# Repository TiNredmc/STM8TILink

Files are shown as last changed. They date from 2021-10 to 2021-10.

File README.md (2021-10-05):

# STM8TILink
The TI grey link clone based on arduino code and half duplex code for stm8s (credits after this line). WIP

# credit 
[DSchndr](https://github.com/DSchndr/serial2ti83) fork of [jw0k repo](https://github.com/jw0k/serial2ti83).

# PCB (at OSHpark).
[rev1 PCB](https://oshpark.com/shared_projects/LCwtGfEf).

# Extra
Due to the physical limitation of STM8S001J3 available pin. I was forced to use the single wire bi-directional UART. which it means that I share TX and RX on same pin (based on [This guy work](http://ficara.altervista.org/?p=4047&doing_wp_cron=1633419018.3038520812988281250000)). The problem starts when host send data to CH330N, since the TX is  connected to schottky barrier diode on cathod side, anode side is connected to STM8 (with 4.7k pull up) and RX pin of CH330N. The loopback "echo" occured everytime the host send command to STM8. The CH330N doesn't ignore the RX line when TX is transmitting. SO the host confused that the RX data is valid (which is not!). In order to solve this problem. I redesigned the PCB with included the SN74LVC1G3157DBVR, SPDT analog switch. I use this IC for bus isolation. CH330N RX will be isolated when MCU isn't send any data to host, it will left unconnected all the time to prevent the loopback echo and confuse host device.

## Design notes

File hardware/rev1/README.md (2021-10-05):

# BOMs

1. x1 BAT43 smd sot-323 diode.  
2. x4 1uF 0603.  
3. x1 CH330N USB to UART 
4. x3 10kOhm or 4.7kOhm 0603.
5. x1 SN74LVC1G3157 SOT-23-6.
6. x1 STM8S001J3.
7. x1 2.5mm 3-pole audio jack (TI plug).

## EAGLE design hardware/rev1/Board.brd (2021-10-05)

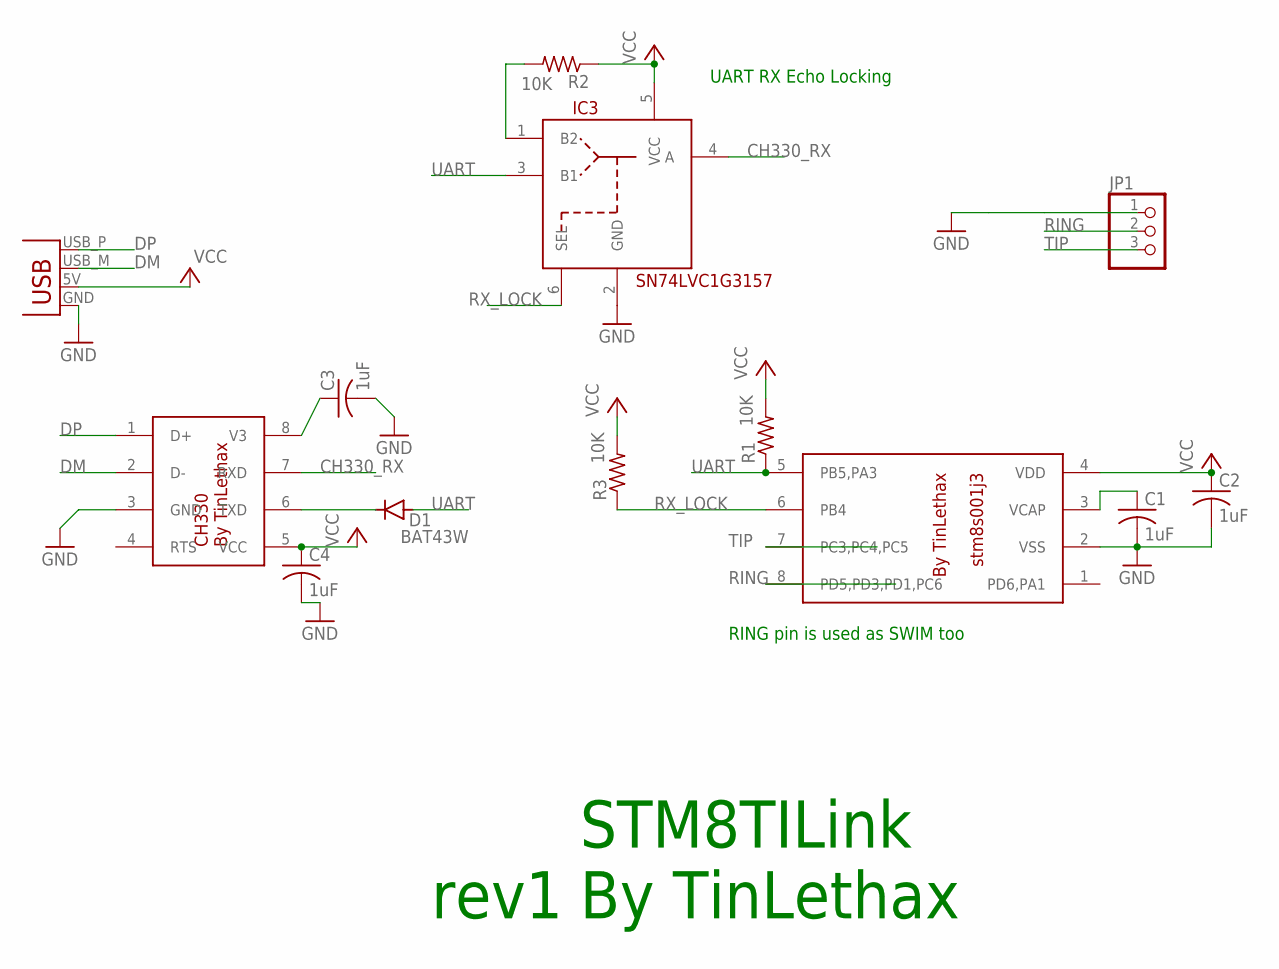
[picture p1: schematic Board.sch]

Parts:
C1, C2, C3, C4: 1uF; C0603
D1: BAT43W; SOD-123_MINI-SMA
IC1: STM8S001J3; SOP8
IC2: CH330; SOIC127P600X150-8N
IC3: SN74LVC1G3157; SOT95P280X145-6N
JP1: PINHD-1X3; 1X03
R1, R2, R3: 10K; R0603
X1: USB_USBPCB; USB_USB-A-PCB

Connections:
CH330_RX: IC2.7 (RXD), IC3.4 (A)
DM: IC2.2 (D-), X1.USB_M (D-)
DP: IC2.1 (D+), X1.USB_P (D+)
GND: C1.2, C2.2, C3.2, C4.2, IC1.2 (VSS), IC2.3 (GND), IC3.2 (GND), JP1.1, X1.GND
unnamed: C1.1, IC1.3 (VCAP)
unnamed: IC3.1 (B2), R2.2
unnamed: C3.1, IC2.8 (V3)
unnamed: D1.C, IC2.6 (TXD)
RING: IC1.8 (PD5,PD3,PD1,PC6), JP1.2
RX_LOCK: IC1.6 (PB4), IC3.6 (SEL), R3.1
TIP: IC1.7 (PC3,PC4,PC5), JP1.3
UART: D1.A, IC1.5 (PB5,PA3), IC3.3 (B1), R1.1
VCC: C2.1, C4.1, IC1.4 (VDD), IC2.5 (VCC), IC3.5 (VCC), R1.2, R2.1, R3.2, X1.5V (VBUS)

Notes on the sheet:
STM8TILink By TinLethax
RING pin is used as SWIM too
rev1
UART RX Echo Locking

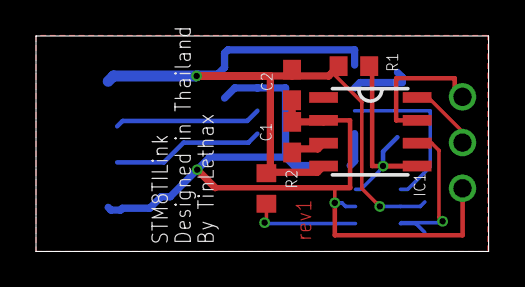
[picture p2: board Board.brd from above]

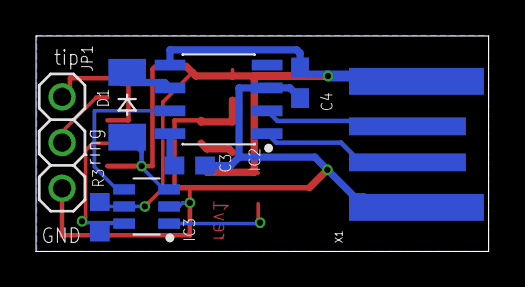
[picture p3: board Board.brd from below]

Board: 2 copper layers, 25.1 x 12.0 mm, 13 parts (8 on the bottom side), 13 nets.

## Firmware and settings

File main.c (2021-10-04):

////////////////////////////////////////////////////////////////////////////////
// FW_VERSION  180701 (yymmdd) - Author: Emilio P.G. Ficara
// Modified to use with STM8TI by TinLethax
// V180701

#include <stm8s.h> // DO NOT USE here generic iostm8s.h (register map is different)
#include <delay.h>
#include <stdint.h>
#include <stdbool.h>

/* TIM4 stuffs */
// arr value for TIM4 millis() interupt.
#define TOP1MS		124 // Tim4 compare top value for 1mS tick
// millis() return value
volatile uint16_t mil = 0;
uint16_t millis(void);

/* UART stuffs */
volatile uint8_t echo = 0; // flag for "RX data is echo of TX"
volatile uint8_t DataFlag = 0;
volatile uint8_t revDat[4] = {0}; //data receive over the UART

/* variables for TI stuffs */

const uint8_t TIP = 5; //PC5 Tip pin
const uint8_t RING = 6; //PC6 Ring pin
const uint8_t TXTIMEOUT = 70; //50ms
const uint8_t RXTIMEOUT = 40; //20ms


#define TI_TIP_IS_HIGH   (PC_IDR & 0x10) 
#define TI_RING_IS_HIGH (PC_IDR & 0x20)

#define TI_TIP_IS_LOW   (~PC_IDR & 0x10)
#define TI_RING_IS_LOW  (~PC_IDR & 0x20)

void TiTipLow(){
	PC_ODR &= ~(1 << TIP);   
}

void TiRingLow(){
	PC_ODR &= ~(1 << RING);   
}

void TiTipOutput(){
	PC_DDR |= (1 << TIP);
	PC_CR1 |= (1 << TIP);
}

void TiRingOutput(){
	PC_DDR |= (1 << RING);
	PC_CR1 |= (1 << RING);
}

void TiTipInputHigh(){
	PC_DDR &= ~(1 << TIP);
	PC_CR1 |= (1 << TIP);
}

void TiRingInputHigh(){
	PC_DDR &= ~(1 << RING);
	PC_CR1 |= (1 << RING);
}


//------------------------------------------------------------------------------
// Serial COMM section

void OutCom(unsigned char c)// sending single byte from calc to PC
{
	echo = 1; // set echo flag (TX will be immediatly received on RX)
	while((UART1_SR & 0x80) == 0); // wait for TXE = 1
	UART1_DR = c; // send char
	while(echo); // wait until echo received
}

//------------------------------------------------------------------------------
// Interrupts section
//
void tim4_millis_irq(void) __interrupt(23)// The millis part, every 1 ms
{
     TIM4_SR = 0x00; // clear irq flag
     mil++;
}

void USART1_RX(void) __interrupt(18){ // Deal with the incoming data from PC and soon will transfer to calc

uint8_t e;

	e = UART1_SR; // read / clear (and ignore) error flags
	e = 1;
	revDat[0] = UART1_DR; // get the char and clear irq
	if(echo){ // if received data is echo of TX
		echo = 0; // turn off flag and don't save
	}else{
		while(UART1_SR & 0x20)// wait until buffer is empty
		revDat[e++] = UART1_DR;// reading all data from host.
		
		DataFlag = 1;// incoming data is not echo but it's data to send to Ti calc.
	}

}

////////////////////////////////////////////////////////////////////////////////
// Stuff for millis(); and TI stuff
//
uint16_t millis(){
return (uint16_t)mil;
}

void sendByte(uint8_t byte){
    uint16_t currentTime;

    for (uint8_t i = 0; i < 8; ++i){
        bool bit = byte & 0x01;
        byte >>= 1;

        //poll both lines until they are both high, which means we're ready to send a bit
        currentTime = millis();
        while (TI_TIP_IS_LOW || TI_RING_IS_LOW){
            if (millis() - currentTime > TXTIMEOUT){
                return;
            }
        }

        if (bit){
            // send a bit by pulling appropriate line low
            TiRingOutput();
            TiRingLow();

            // wait for opposite line to become low
            currentTime = millis();
            while (TI_TIP_IS_HIGH){
                if (millis() - currentTime > TXTIMEOUT){
                    TiRingInputHigh();// set to input pull up.
                    return;
                }
            }

            // release our line
            TiRingInputHigh();

            // wait for opposite line to become high
            currentTime = millis();
            while (TI_TIP_IS_LOW){
                if (millis() - currentTime > TXTIMEOUT){
                    return;
                }
            }

        }else{
            // send a bit by pulling appropriate line low
            TiTipOutput();
            TiTipLow();

            // wait for opposite line to become low
            currentTime = millis();
            while (TI_RING_IS_HIGH){
                if (millis() - currentTime > TXTIMEOUT){
                    TiTipInputHigh();
                    return;
                }
            }

            // release our line
            TiTipInputHigh();

            // wait for opposite line to become high
            currentTime = millis();
            while (TI_RING_IS_LOW){
                if (millis() - currentTime > TXTIMEOUT){
                    return;
                }
            }

        }
  }
}

bool getByte(uint8_t *byte){
   uint16_t currentTime;
    uint8_t result = 0;
    for (uint8_t i = 0; i < 8; ++i)
    {

        currentTime = millis();
        while (TI_RING_IS_HIGH && TI_TIP_IS_HIGH)
        {
            if (millis() - currentTime > RXTIMEOUT)
            {
                return false;
            }
        }
        
        bool bit = TI_RING_IS_LOW;
        result >>= 1;
        
        if (bit)
        {
            //ourLine = TIP;
            //oppositeLine = RING;
            result |= 0x80; //bits are always transmitted LSb first (least significant bit)
            
            // acknowledge a bit by pulling appropriate line low
            TiTipOutput();
            TiTipLow();
            
            //wait for opposite line to become high
            currentTime = millis();
            while (TI_RING_IS_LOW)
            {
                if (millis() - currentTime > RXTIMEOUT)
                {
                    TiTipInputHigh();// Set to input pull-up mode
                    return false;
                }
            }

            // release our line
            TiTipInputHigh();
        }
        else
        {
            //ourLine = RING;
            //oppositeLine = TIP;
            
            // acknowledge a bit by pulling appropriate line low
            TiRingOutput();
            TiRingLow();
            
            //wait for opposite line to become high
            while (TI_TIP_IS_LOW)
            {
                if (millis() - currentTime > RXTIMEOUT)
                {
                    TiRingInputHigh();

                }
            }

            // release our line
            TiRingInputHigh();// set input pull up.
            
        }
    }

    *byte = result;
return true;

}

void main(void)
{
	CLK_CKDIVR = 0x00;  // Set the frequency to 16 MHz

	delay_ms(1000);// startup delay for SWIM programming before take over the SWIM pin for other usage.

	PA_ODR |= 0x08; // 0000.1000 All PA data is 0 except PA3 (UART_TX)
	PA_DDR |= 0x08; // 0000.1000 PA.3 is output
	PA_CR1 |= 0x00; // 0000.0000 PA.3 is open drain

	PB_DDR |= (1 << 4);// PB 4 as output open-drain
	PB_ODR |= (1 << 4);// immediately release pull down. 

   	 //configure both lines as input and enable pull-up resistors
	//PC_DDR = (0 << TIP) | (0 << RING);
	PC_CR1 |= (1 << TIP) | (1 << RING);
	//PC_CR2 = (0 << TIP) | (0 << RING); 

	// init the uart1 in the single pin half duplex mode on PA3 (pin 5 on SOP8)
	UART1_CR1 = 0x00; // 0000.0000 Enable UART 8bit, no parity
	UART1_CR3 = 0x00; // 0000.0000 1 stop bit
	UART1_CR5 = 0x08; // 0000.1000 no dma, half duplex
	UART1_BRR2 = 0x03; // set 9600 BPS
	UART1_BRR1 = 0x68; //
	UART1_CR2 = 0x2C; // 0010.1100 Enable RX irq, Enable TX and RX

	// Timer4 setup for millis()-likes function.
	TIM4_PSCR = 0x07; // fCK_CNT = fCK_PSC/2**PSCR (2**7=128)
	TIM4_ARR = TOP1MS; // set TOP value (reset cnt) for 1mS
	TIM4_SR = 0x00;
	TIM4_IER |= 0x01;
	TIM4_CR1 |= 0x01;

  	 __asm__("rim");

	while(1){
		while(DataFlag){
			sendByte(revDat[0]);
			sendByte(revDat[1]);
			sendByte(revDat[2]);
			sendByte(revDat[3]);	
			DataFlag = 0;// clear data receipt flag.
		}

		uint8_t byteFromCalc = 0;
		if (getByte(&byteFromCalc)){
			PB_ODR &= ~(1 << 4);// pull low to switch from B2 to B1 and connect CH330's RX to MCU pin.
			OutCom(byteFromCalc);
			PB_ODR |= (1 << 4);// release to switch back to B2 (has a pul up for CH330's RX pin).
		}
	}
}
